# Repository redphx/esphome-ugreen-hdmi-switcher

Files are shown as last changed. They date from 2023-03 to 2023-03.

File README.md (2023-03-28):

# ESPHome UGREEN HDMI Switcher
Control UGREEN HDMI Switcher/Splitter over WiFi using ESPHome. You can still control it with the physical button on top of the device (it also changes the state in Home Assistant device).  
Demo video: https://youtu.be/F_oZo9kNero  

⚠️ **DISCLAIMER:** Nobody but you is responsible for any damage this mod may cause.  

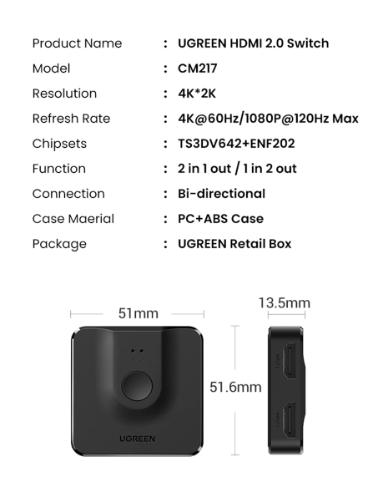
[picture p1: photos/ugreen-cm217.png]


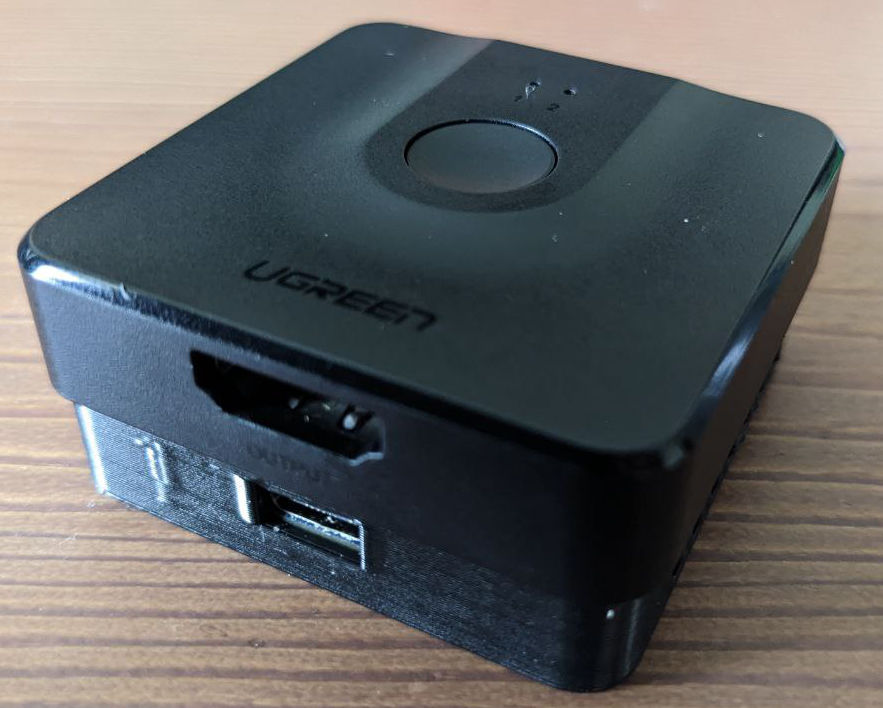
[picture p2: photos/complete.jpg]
  
  
You can put the USB port to the other side if you want to.  

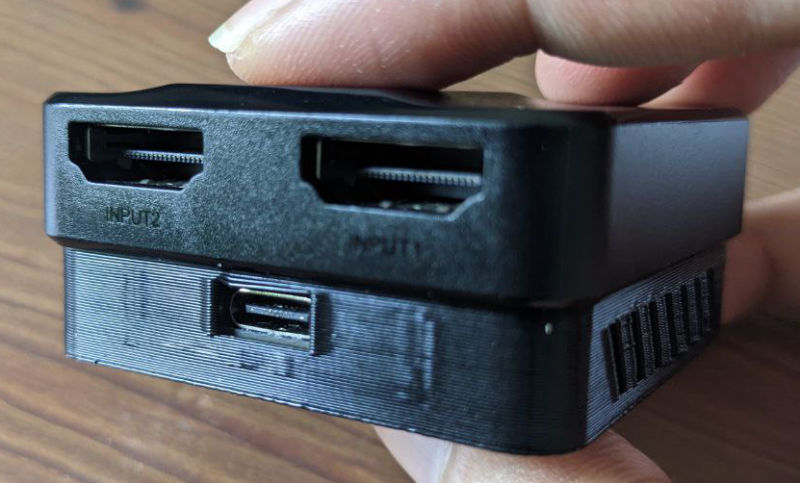
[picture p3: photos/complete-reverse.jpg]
  

## Parts  
1. UGREEN HDMI 2.0 Switch CM217 (~12 USD, [Aliexpress](https://www.aliexpress.com/item/32968528447.html)).  The one I got was manufactured in 2019.  
2. Wemos LOLIN D1 Mini (~4 USD, [Aliexpress](https://www.aliexpress.com/item/32529101036.html)).  Tested with version 4.0.  
3. Two small electrical wires. I use the 24 AWG one.
4. Soldering station.  
5. Glue gun.  
6. 3D Printer.  
7. Anything with an USB Type C male port (cable, adapter).
  
## Disassembly  
1. Peel off the pad at the bottom and unscrew the screws. We'll need these two screws later.  
2. Use something like a guitar pick to pry up the back. Don't worry if you damage the bottom part as you won't need it.  
3. Take the board out.
  
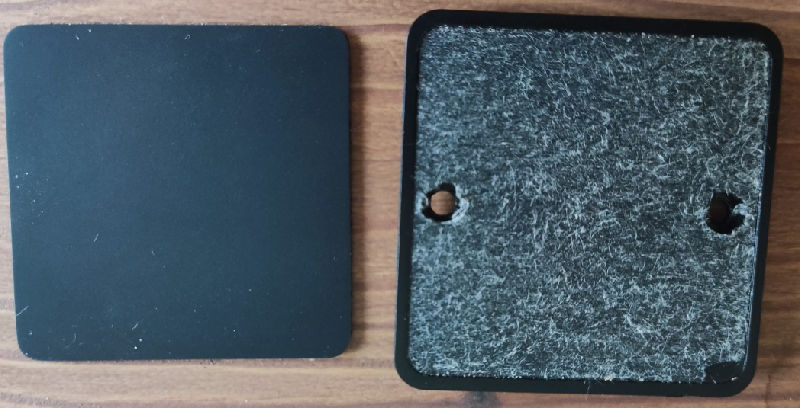
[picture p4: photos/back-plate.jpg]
  
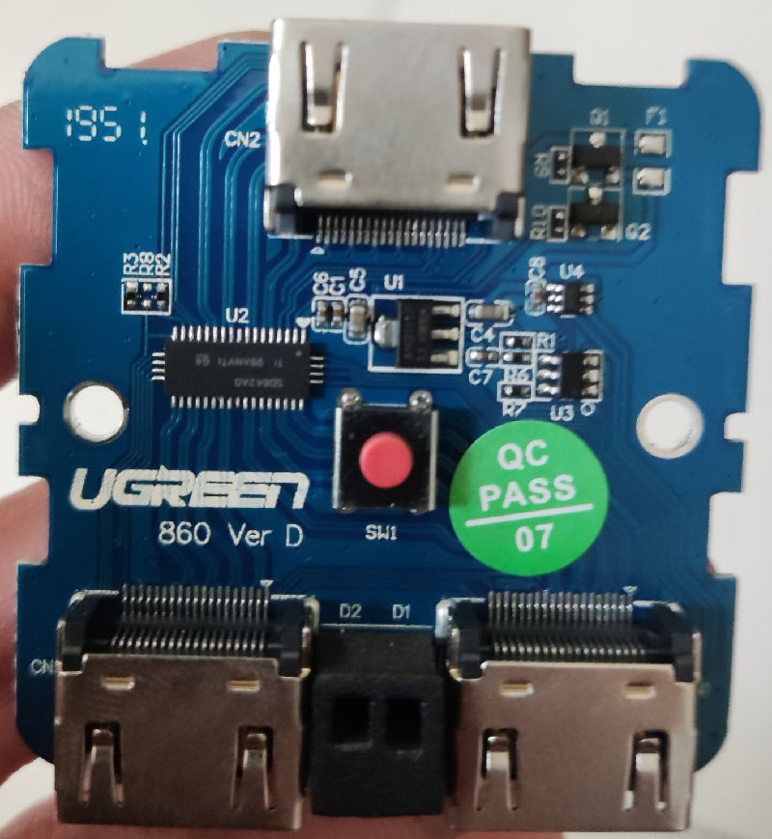
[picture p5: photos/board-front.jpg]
  
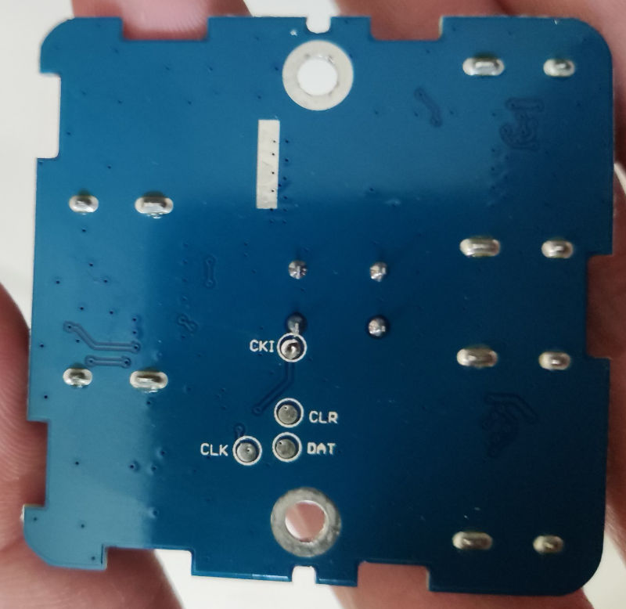
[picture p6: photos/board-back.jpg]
  

## Wiring
You'll only need two pins:
- Connect CKI port with Pin #2 (control the HDMI switching).  
- Connect DAT port with Pin #4 (contain value of the current HDMI port).  
- ⚠️ IMPORTANT
  - Connect the wires to the upper side of the board.  
  - Just to be safe, don't let the wire touch the pin next to CKI serial port.  
  - Make sure the wires are long enough so the USB port can be either put on the left or the right side.  

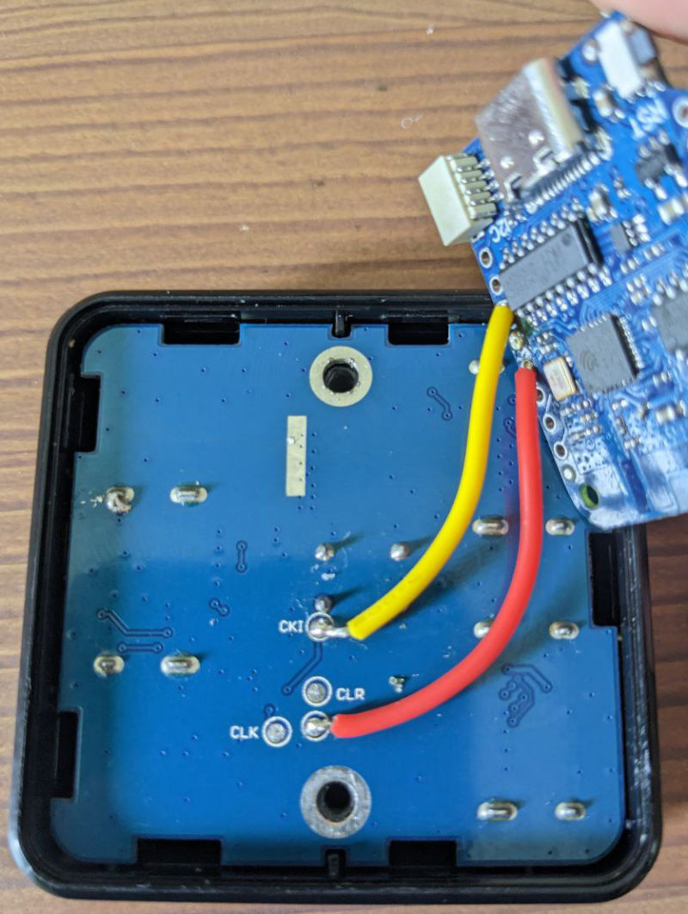
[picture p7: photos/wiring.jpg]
  

## 3D Printing
3D files are in `3d-files` folder.
My settings in Cura:
- Support: Tree  
- Layer height: 0.25  
- Layer width: 0.5  

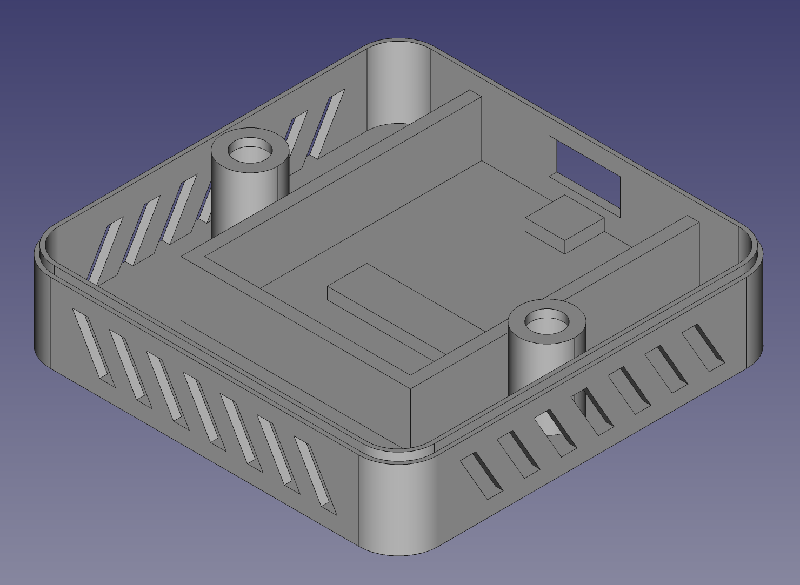
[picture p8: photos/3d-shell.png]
  

## Assembly
1. Put the board into the case.  
2. Plug the USB Type C cable into the board to make sure that everything is lined up.  
3. Use glue gun to make the board stay in place.  
4. Put in the upper half then screw everything in together.  

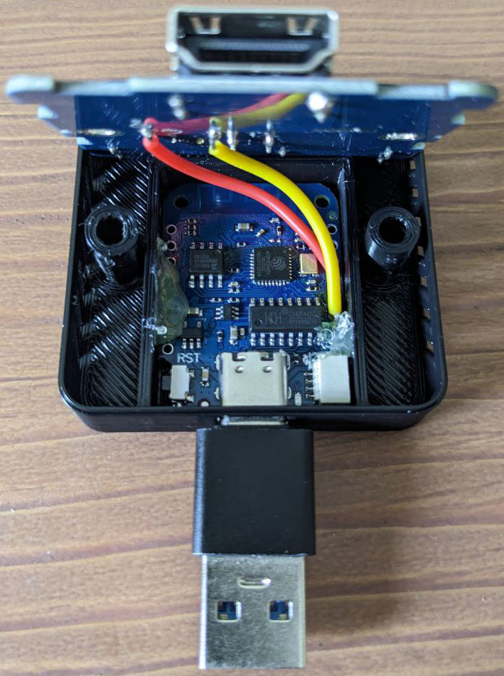
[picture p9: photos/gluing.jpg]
  

## ESPHome code
Flash the board with ESPHome using the code in [`esphome-code.yaml`](esphome-code.yaml).

## Home Assistant Device
If everything works you should see something like this in Home Assistant.  
- Use `Toggle HDMI Port` button to switching between the ports.  
- Use `HDMI Port` sensor to know the current activated port. It can be either `hdmi1` or `hdmi2`.  

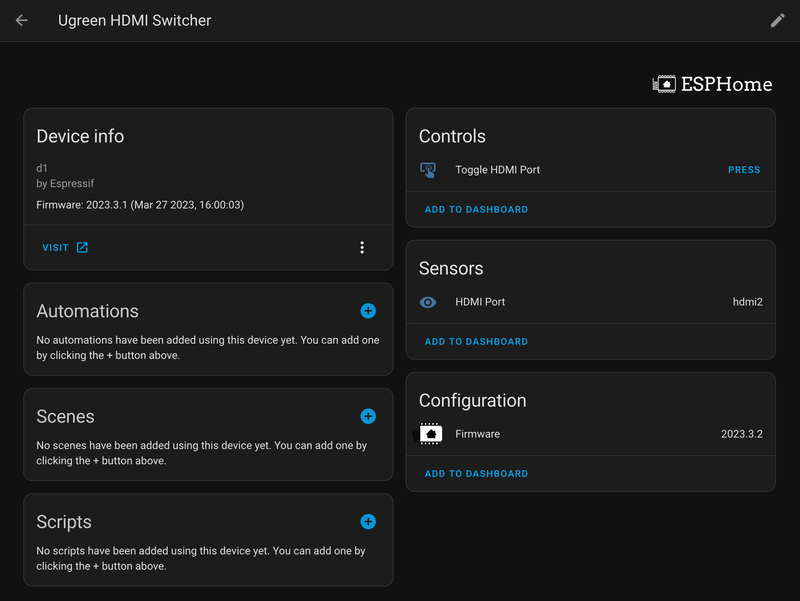
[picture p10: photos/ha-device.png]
  

### Thanks for reading. Good luck!

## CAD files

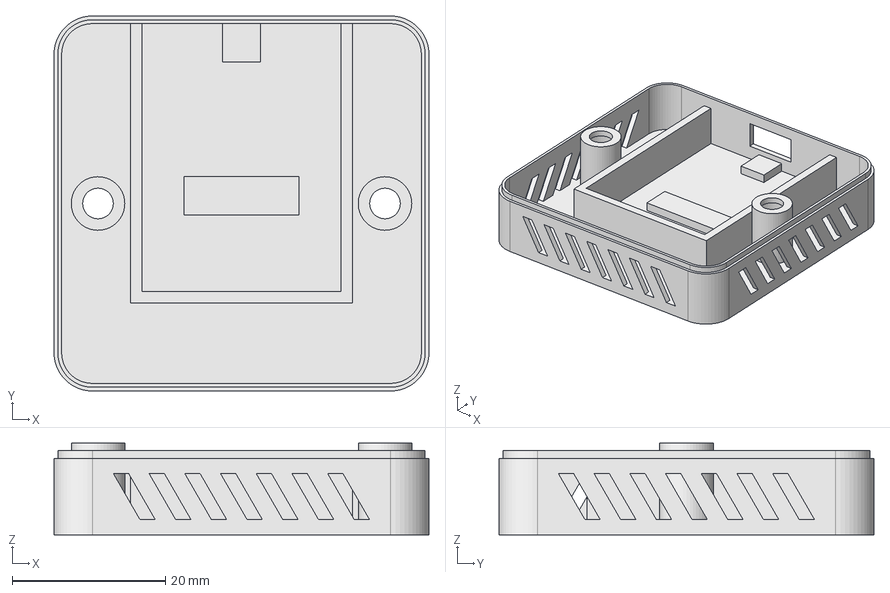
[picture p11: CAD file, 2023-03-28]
3d-files/ugreen-hdmi-switcher.FCStd
49.0 x 49.0 x 12.0 mm

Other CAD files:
3d-files/ugreen-hdmi-switcher.3mf

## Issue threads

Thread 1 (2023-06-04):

Double press?

nwithan8, 2023-06-04:
Everytime I hit the "Toggle" button, it switches between the two ports in rapid succession, rather than staying on the next port.

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

Logs via ESPHome:
```
[D][button:010]: 'Toggle HDMI Port' Pressed.
[D][button:010]: 'Toggle HDMI Port' Pressed.
[D][binary_sensor:036]: 'HDMI Port Status': Sending state OFF
[D][text_sensor:064]: 'HDMI Port': Sending state 'hdmi1'
[D][binary_sensor:036]: 'HDMI Port Status': Sending state ON
[D][text_sensor:064]: 'HDMI Port': Sending state 'hdmi2'
[D][button:010]: 'Toggle HDMI Port' Pressed.
[D][binary_sensor:036]: 'HDMI Port Status': Sending state OFF
[D][text_sensor:064]: 'HDMI Port': Sending state 'hdmi1'
[D][binary_sensor:036]: 'HDMI Port Status': Sending state ON
[D][text_sensor:064]: 'HDMI Port': Sending state 'hdmi2'
```

ildar7070, 2023-09-28:
I have the same problem. Also it shows always the status 'hdmi2'. Even if I press the button manually on the device to switch the inputs.

KR4DIO, 2023-11-14:
@nwithan8 and @ildar7070 -- Connect a wire from the ground pin on your ESP board to ground on the HDMI switch. I used one of the HDMI port lugs. Note that I also switched the "DAT" connection from D4 to D1, as my ESP board didn't seem like having that pin pulled low during boot.

See attached image:
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

I changed the board type and pin numbers to match my particular board/connections:
```
esphome:
  name: esphome-web-d739ff
  friendly_name: hdmi-switch

esp8266:
  board: d1_mini_lite

# Enable logging
logger:

# Enable Home Assistant API
api:
  encryption:
    key: "xxxxxxx"

ota:

wifi:
  ssid: !secret wifi_ssid
  password: !secret wifi_password

  # Enable fallback hotspot (captive portal) in case wifi connection fails
  ap:
    ssid: "Esphome-Web-xxxxxx"
    password: "xxxxxxxxxxxx"

captive_portal:

output:
  - platform: gpio
    pin:
      number: D2
      inverted: true
    id: 'output_toggle'

button:
  - platform: output
    name: "Toggle HDMI Port"
    output: 'output_toggle'
    duration: 500ms

binary_sensor:
  - platform: gpio
    name: "HDMI Port Status"
    id: hdmi_pin
    internal: true
    pin: D1
    publish_initial_state: true
    on_state:
      then:
        - lambda: !lambda |-
            if (id(hdmi_pin).state) {
              id(hdmi_port).publish_state("hdmi2");
            } else {
              id(hdmi_port).publish_state("hdmi1");
            }

text_sensor:
  - platform: template
    id: hdmi_port
    name: "HDMI Port"
```

ildar7070, 2023-11-14:
This did the trick for me. Thank you for providing help on this. I think we can close this issue

djjoereece94, 2024-05-03:
I'm still having a problem with this if anyone can help me, It keeps jumping back to the same port. Ive tried adding the connection between the GND pin and a lug on the HDMI and this just stops the device from functioning alltogether, it seems to set the LOLIN D1 into flash mode. Any help would be grately appreciated.

KR4DIO, 2024-05-03:
> I'm still having a problem with this if anyone can help me, It keeps jumping back to the same port. Ive tried adding the connection between the GND pin and a lug on the HDMI and this just stops the device from functioning alltogether, it seems to set the LOLIN D1 into flash mode. Any help would be grately appreciated.

If connecting the grounds together makes the esp8266 go into flash mode, you have connected something wrong. Make sure you didn't connect pin D3 to anything.

djjoereece94, 2024-05-03:
> > I'm still having a problem with this if anyone can help me, It keeps jumping back to the same port. Ive tried adding the connection between the GND pin and a lug on the HDMI and this just stops the device from functioning alltogether, it seems to set the LOLIN D1 into flash mode. Any help would be grately appreciated.
>
> If connecting the grounds together makes the esp8266 go into flash mode, you have connected something wrong. Make sure you didn't connect pin D3 to anything.

I have just double checked, nothing connected to D3, I am new to this so maybe im missing somethig
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

djjoereece94, 2024-05-04:
Update, I have am now using pin 5 instead of pin 2 and am no longer stuck in flash mode, however when the ground is connected from the GND pin to the ground on the HDMI switch I receive the message instead of the port switching.
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

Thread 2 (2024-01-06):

Unable to open print files.

wasyl00, 2024-01-06:
Can anyone confirm that the print files are working? I tried 3mf but prusa slicer throws error. I then downloaded freecad for the other file but it doesnt work as well. Any ideas ho to open any of them? Thanks

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

wasyl00, 2024-01-06:
Nevermind I'm dumb

Closed 2024-01-06.

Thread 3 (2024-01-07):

I made low profile altarnative case

wasyl00, 2024-01-07:
Hello, just wanted to share low profile case I made for this fantastic project. Cheers

https://www.printables.com/model/710920-home-assistant-hdmi-switcher-low-profile-case

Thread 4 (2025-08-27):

New PCB version with different chip

ThomDietrich, 2025-08-27:
Hey guys, I've ordered one of these on Amazon last week. https://www.amazon.de/dp/B07H7JCCKM

They are now selling a new version of it. On the back it reads "Model: CM217" and the main chip was replaced by the [ASW3642](https://uploadcdn.oneyac.com/attachments/files/brand_pdf/grandmicro/C1/51/ASW3642-DS-EN-V08-202306.pdf). Your old logic and soldering instructions won't work with this model.

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

Good news 😃 I've soldered a testing wire to SEL and am certain that I'll be able to make this work. For today I just did a quick test but I would bet that SEL is connected to a pull-down or pull-up resistor, as I can temporarily switch channels by connecting to one of the pins (it was either VCC or GND). I am not sure yet how they realized the permanent switching using the button input.

My primary goal is to integrate the device in Home Assistant, hence might indeed disable/hide the on-board button. I'll keep you posted.
